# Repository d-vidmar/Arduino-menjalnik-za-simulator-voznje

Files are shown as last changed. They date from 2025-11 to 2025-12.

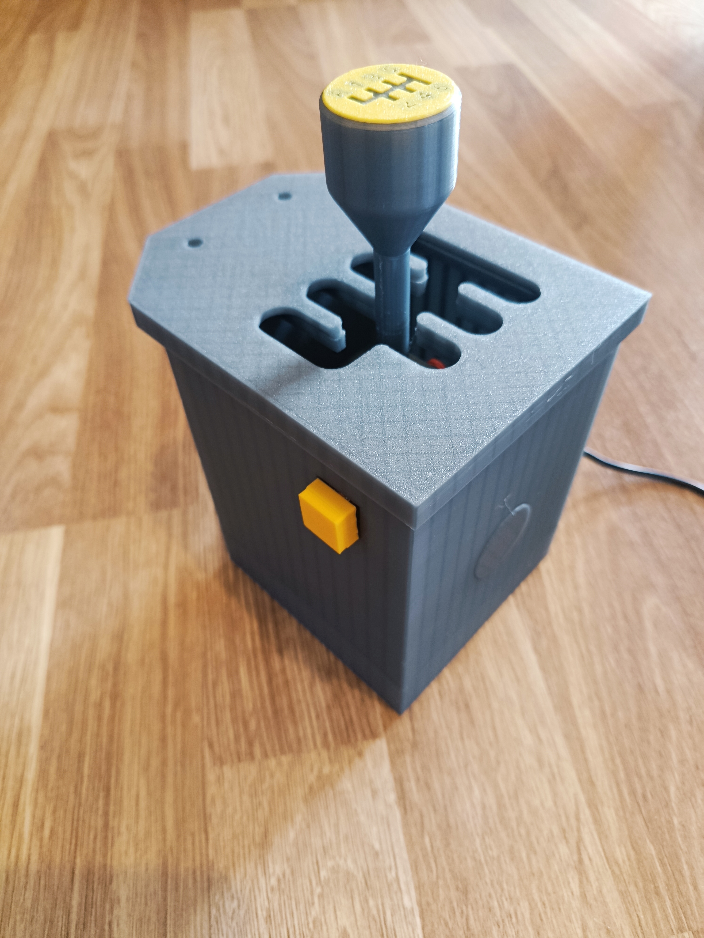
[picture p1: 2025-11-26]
slika.jpg

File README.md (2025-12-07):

# Arduino-menjalnik-za-simulator-voznje
Modeli za 3D tiskalnik in Arduino koda, s katero lahko Arduino Leonardo spremenite v menjalnik za simulator vožnje s 6 prestavami + R in dodatnim gumbom!

POMEMBNO: Uporabite lahko le Arduino Leonardo, Micro ali druge mikrokontrolerje, ki so na [TEM SEZNAMU](https://github.com/MHeironimus/ArduinoJoystickLibrary/wiki/Supported-Boards). Arduino Uno NE dela!
Potrebujete tudi [TO KNJIŽNJICO](https://github.com/MHeironimus/ArduinoJoystickLibrary/archive/master.zip). <br/><br/>

## Seznam stvari, ki jih potrebujete (poleg 3D tiskalnika in spajkalnika)
- 1x Arduino Leonardo / Pro Micro / drugi mikrokontroler z zgornjega seznama
- 2x potenciometer 10kOhm ([amazon](https://www.amazon.de/dp/B00H969CM0?ref_=pe_111929571_1111661321_t_fed_asin_title&th=1))
- 1x tipka za mehansko tipkovnico 
- 1x navojna palica M6 dolžine 8,5cm
- 2x elastika
- nekaj izoliranih tankih žic za povezave <br/><br/>

**Vsa navodila najdete v pdf datoteki "Navodila za izdelavo", vse povezave pa v datoteki "povezave.png".** <br/><br/>
Tako naj bi izgledal sestavlje menjalnik: <br/>
menjalnik_projekt

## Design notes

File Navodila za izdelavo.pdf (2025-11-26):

# Navodila za izdelavo

1. Natisnite vse dele.
2. Na oba potenciometra s spajkalnikom pritrdite žice, kot je na shemi. Žic še ne povezujte na Arduino.
3. V del »glavniDel« vstavite del »ročica« tako, kot je prikazano na sliki.

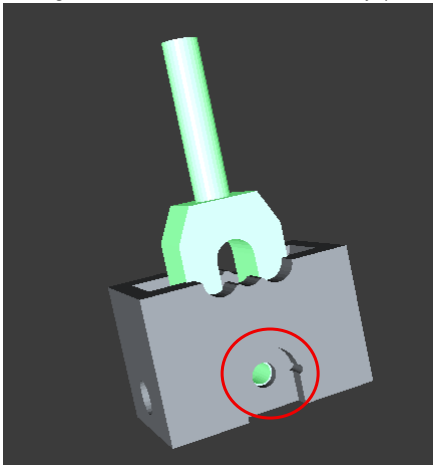
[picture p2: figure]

4. V označen del na sliki vstavite potenciometer tako, da se ob premikanju ročice vrti glava potenciometra.
5. Na drugo stran »glavnega dela« vstavite del »čep1«.
6. V odprtino »ročice« vstavite »čep3«. Elastiko vstavite v zarezo na eni strani »čepa3«, nato pojdite okoli »glavnega dela« in jo vstavite v zarezo na drugem koncu »čepa3«. (Glej sliko)

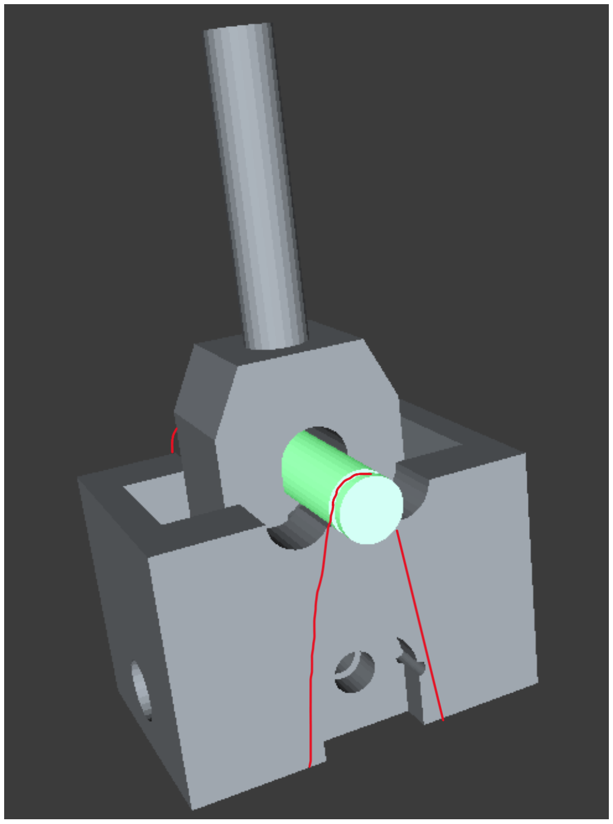
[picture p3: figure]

7. V manjšo, 6mm luknjo na »glavnem delu« vstavite glavo drugega potenciometra.
8. Drugi del potenciometra prilepite v označen del na »ohišju« nasproti večje luknje (glej spodnji sliki).

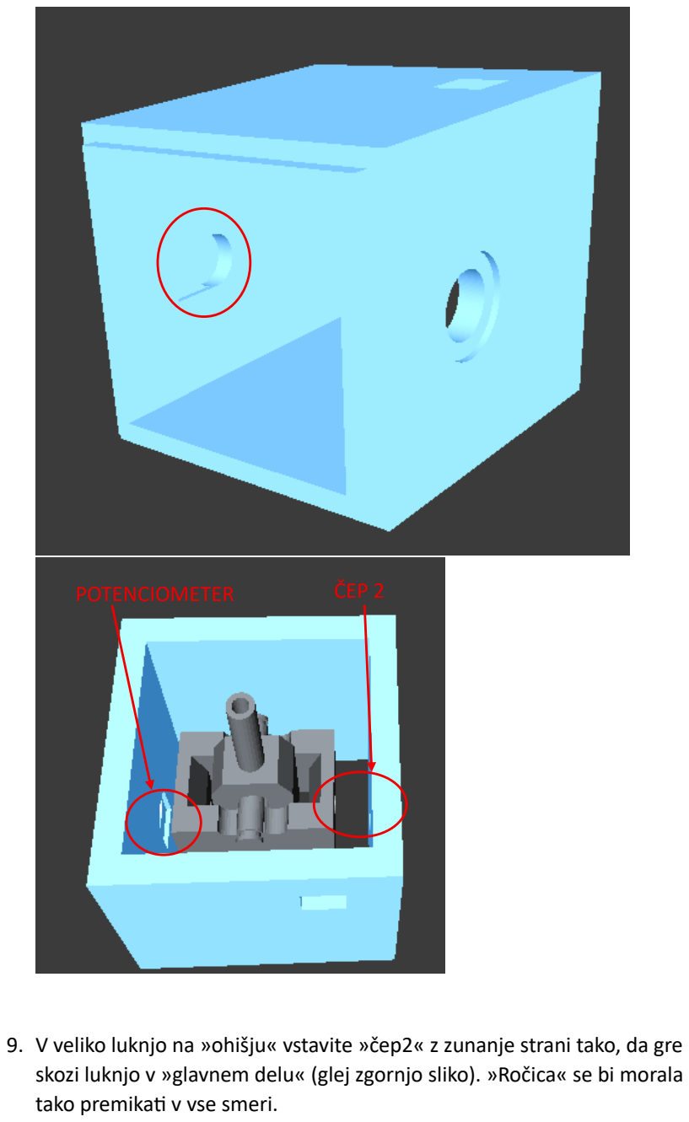
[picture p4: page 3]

9. V veliko luknjo na »ohišju« vstavite »čep2« z zunanje strani tako, da gre skozi luknjo v »glavnem delu« (glej zgornjo sliko). »Ročica« se bi morala tako premikati v vse smeri.

POTENCIOMETER

ČEP 2

10. Na tipko s spajkalnikom pritrdite žici. Nato jo z zunanje strani vstavite v kvadratno odprtino na »ohišju«. Na tipko pritrdite še del »tipka« in preverite, da je tipko mogoče pritisniti. Če se tipka zatika, jo je potrebno malo pobrusiti.
11. V »dno« pritrdite Arduino. Skozi luknjo na »dnesu« vstavite kabel in ga vtaknite v Arduino. Če se luknje za pritrditev na Arduinu ne prilegajo, ga lahko enostavno zalepite s silikonom.
12. Žice povežite na Arduino, kot je prikazano na shemi »povezave.png«.
13. »Dno« pritrdite na spodnji del »ohišja«, kjer je rob. »Dno« je pravilno obrnjeno tako, da je luknja za kabel na nasprotni strani od »tipke«. »dno« gre na »ohišje« zelo na tesno, če pa sploh ne gre, ga lahko malo pobrusite.
14. Na zgornjo stran »ohišja« pritrdite »zgornji del« tako, da je rob, ki ima dve luknji za pritrditev, na nasprotni strani od velike luknje na »ohišju«. Tudi ta del gre zelo na tesno, zato lepljenje verjetno ne bo potrebno.
15. V luknjo v »ročki« vstavite navojno palico M6 2,5 – 3cm globoko. »Ročko« z navojno palico nato vstavite v luknjo v »Ročici«. Če se »Ročka« vrti, jo lahko zalepite.

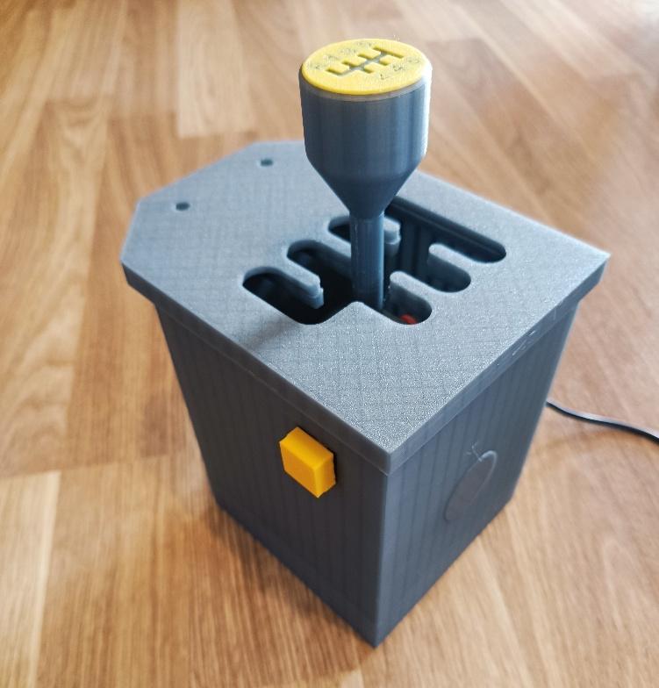
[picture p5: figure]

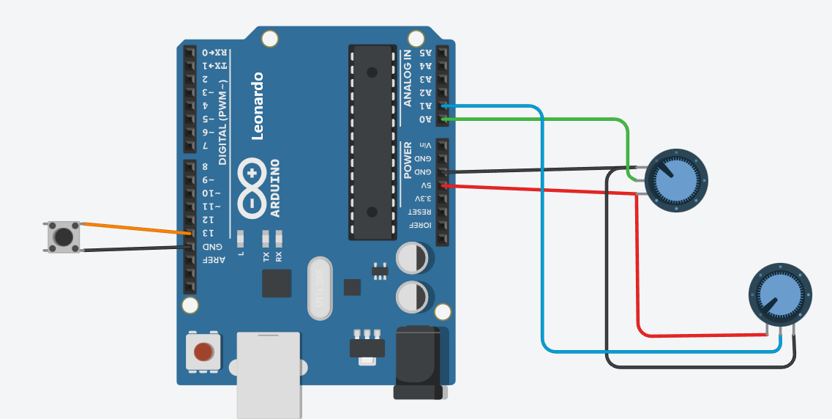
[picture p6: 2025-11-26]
povezave.png

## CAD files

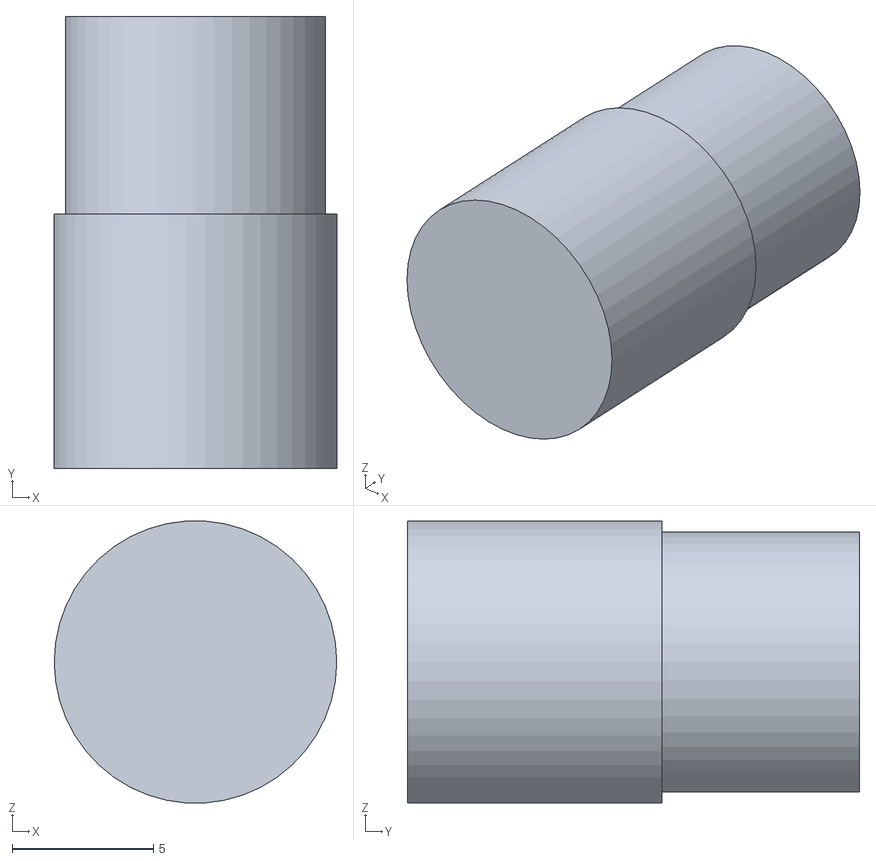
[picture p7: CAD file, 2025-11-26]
3DModeli/cep1.stl
10.0 x 16.0 x 9.98

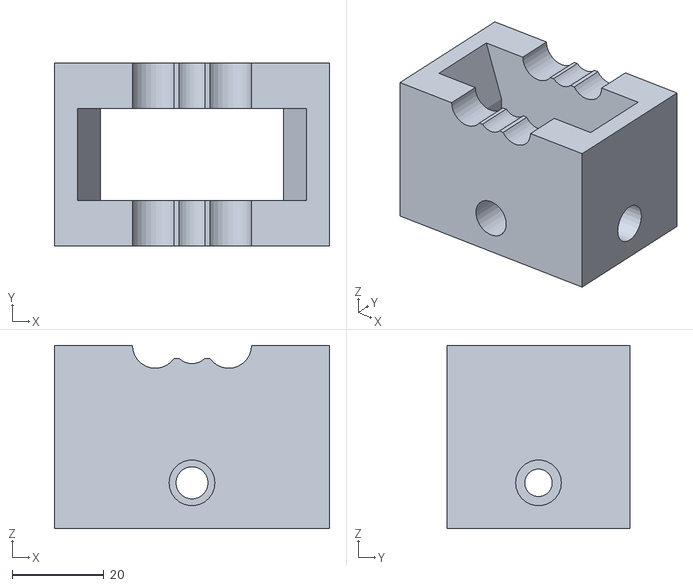
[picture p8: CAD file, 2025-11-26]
3DModeli/glavniDel.stl
60.0 x 40.0 x 40.0

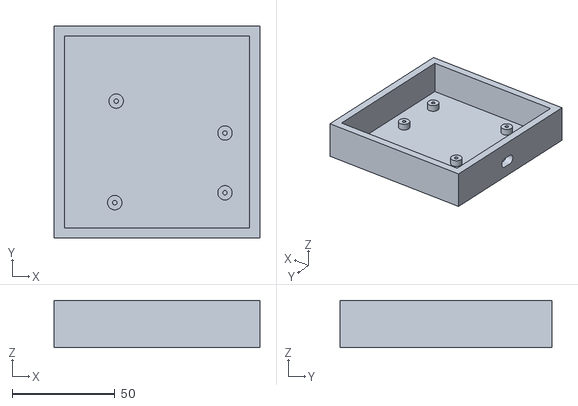
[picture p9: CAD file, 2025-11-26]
3DModeli/dno.stl
100.0 x 103.0 x 23.0

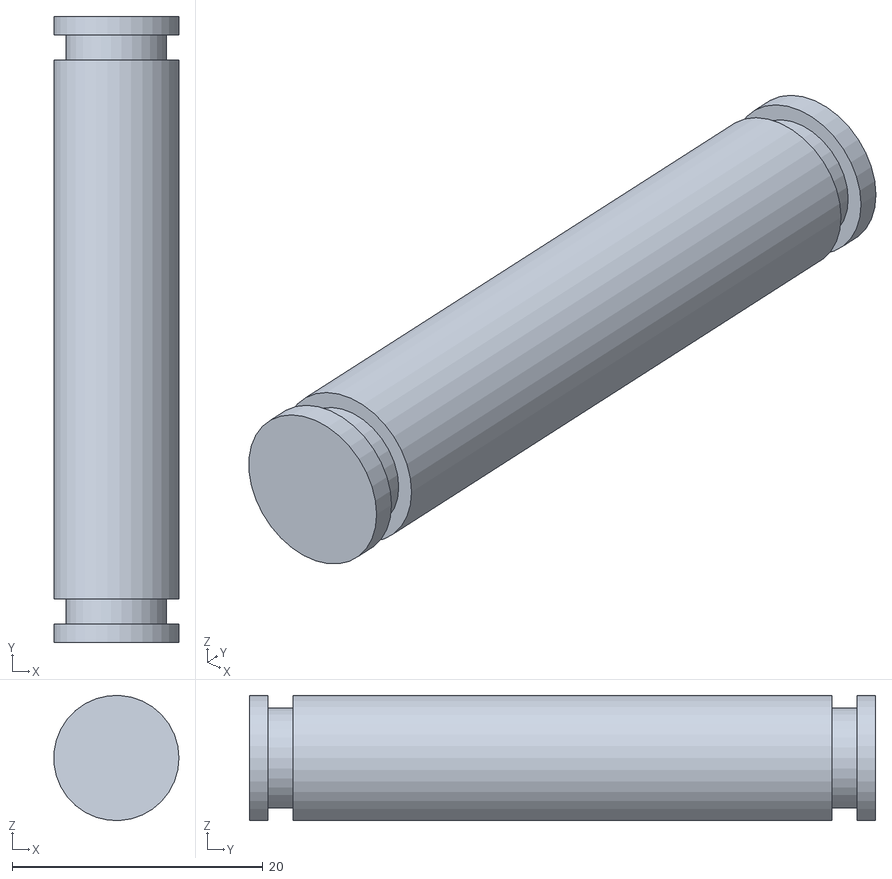
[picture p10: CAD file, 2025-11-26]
3DModeli/cep3.stl
9.98 x 50.0 x 9.99

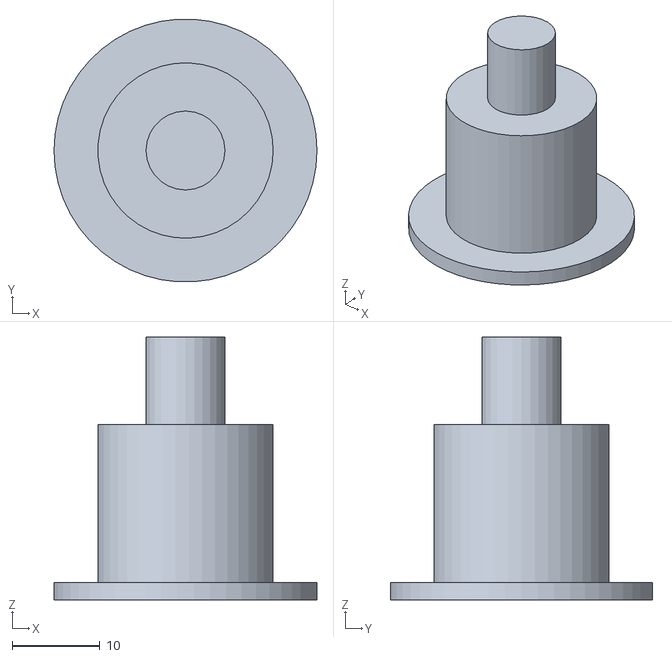
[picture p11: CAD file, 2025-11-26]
3DModeli/cep2.stl
30.0 x 29.9 x 30.0

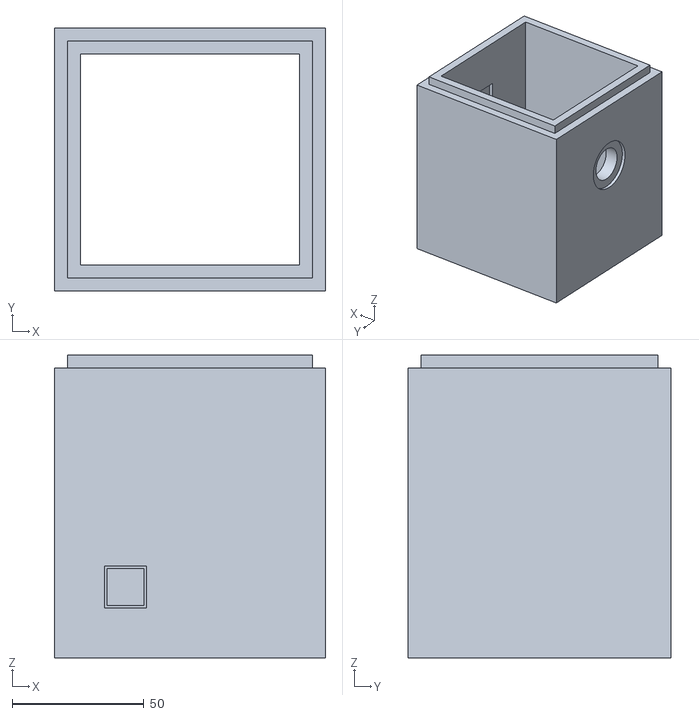
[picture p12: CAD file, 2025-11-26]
3DModeli/ohisje.stl
103.0 x 100.0 x 115.0

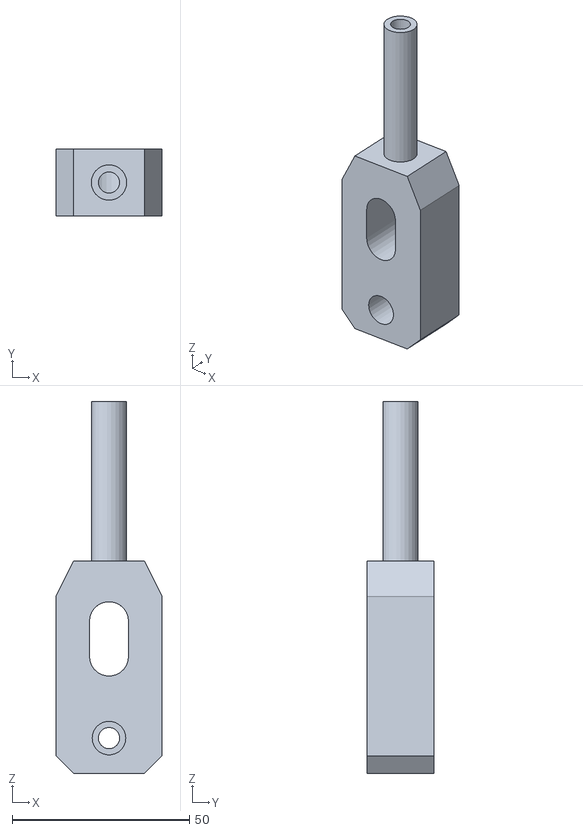
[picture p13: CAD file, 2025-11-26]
3DModeli/rocica.stl
30.0 x 19.0 x 105.0

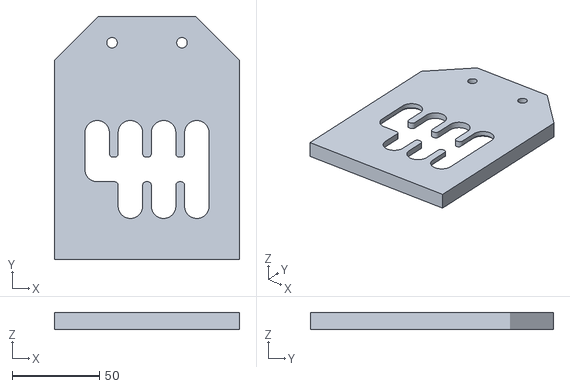
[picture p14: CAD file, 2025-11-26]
3DModeli/zgornjiDel.stl
106.0 x 139.0 x 10.0

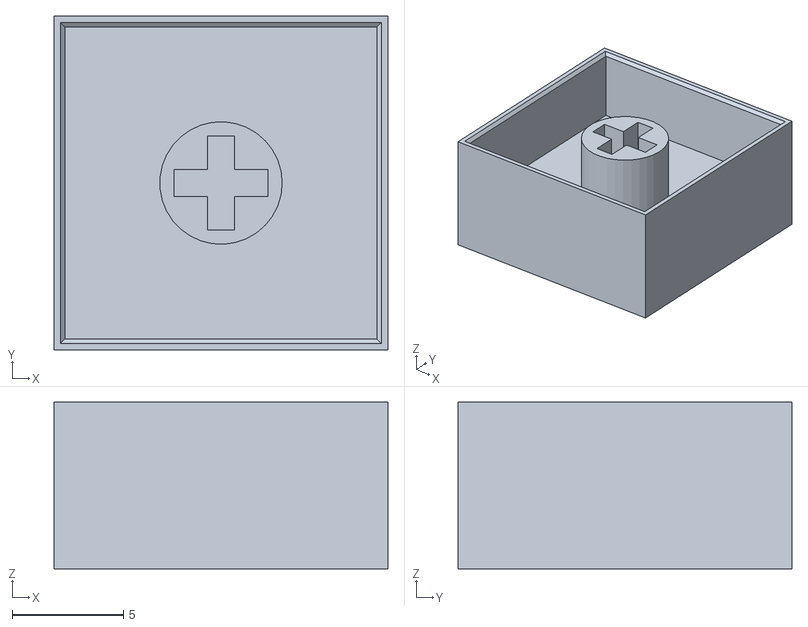
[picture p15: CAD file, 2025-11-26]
3DModeli/tipka.stl
15.0 x 15.0 x 7.50

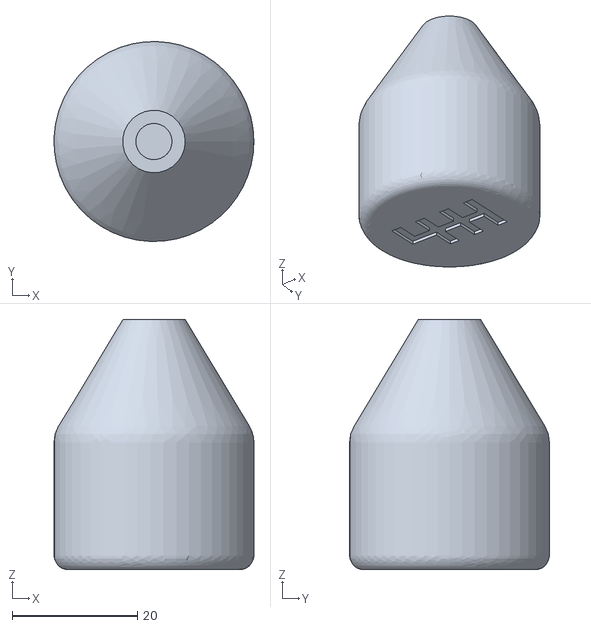
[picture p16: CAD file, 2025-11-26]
3DModeli/rocka.stl
32.0 x 32.0 x 40.0

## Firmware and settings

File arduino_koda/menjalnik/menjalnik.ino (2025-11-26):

// *** POMEMBNO ***
// Najprej je potrebno prenesti knjižnjico s te povezave: https://github.com/MHeironimus/ArduinoJoystickLibrary/archive/master.zip

#include "Joystick.h"

Joystick_ Joystick;

void setup() {
  pinMode(A0, INPUT);
  pinMode(A1, INPUT);
  pinMode(13, INPUT_PULLUP);
  Joystick.begin();
}

void loop() {
  int v=analogRead(A0);
  int h=analogRead(A1);
  if(digitalRead(13)==LOW){ //tipka pri strani
    Joystick.setButton(7,true);
  }
  else{
    Joystick.setButton(7,false);
  }
  
  //spremeni vrednosti pogojev tako, da ustrezajo vrednostim "v" in "h" potenciometrov, ko je prestava v določenem položaju
  //vrednosti "v" in "h" za tvoj primer dobiš tako, da odpreš datoteko "menjalnik.ino" in slediš navodilom.
  if(v<460&&h<480){ //R |spremeni pogoj tako, da je izpolnjen, ko je prestava v R položaju; enako velja za druge prestave
    Joystick.setButton(6,true);
    for(int i=0; i<6; i++){
      Joystick.setButton(i,false);
    }
  }
  else if(v<460&&h>480&&h<525){//1
    Joystick.setButton(0,true);
    for(int i=1; i<7; i++){
      Joystick.setButton(i,false);
    }
  }
  else if(v>490&&h>480&&h<525){//2
    Joystick.setButton(1,true);
    for(int i=0; i<7; i++){
      if(i!=1){
        Joystick.setButton(i,false);
      }
    }
  }
  else if(v<460&&h>525&&h<575){//3
    Joystick.setButton(2,true);
    for(int i=0; i<7; i++){
      if(i!=2){
        Joystick.setButton(i,false);
      }
    }
  }
  else if(v>490&&h>525&&h<575){//4
    Joystick.setButton(3,true);
    for(int i=0; i<7; i++){
      if(i!=3){
        Joystick.setButton(i,false);
      }
    }
  }
  else if(v<460&&h>575){//5
    Joystick.setButton(4,true);
    for(int i=0; i<7; i++){
      if(i!=4){
        Joystick.setButton(i,false);
      }
    }
  }
  else if(v>490&&h>575){//6
    Joystick.setButton(5,true);
    for(int i=0; i<7; i++){
      if(i!=5){
        Joystick.setButton(i,false);
      }
    }
  }
  else{ //N
    for(int i=0; i<7; i++){
      Joystick.setButton(i,false);
    }
  }

  delay(50);

}

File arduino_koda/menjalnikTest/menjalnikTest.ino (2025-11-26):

// *** NAVODILA ***
// Naloži kodo na arduino in odpri "Serial monitor"
// Najprej pusti menjalnik v N in nato pritisni tipko pri strani, da se izpiše vrednost "v" in "h"
// Prestavi v položaj R in nato pritisni tipko pri strani, da se izpiše vrednost "v" in "h" pri prestavi R
// Tako naprej nadaljuj za prestave od 1 do 6 PO VRSTI in vsakič pritisni tipko, da se izpišejo vrednosti "v" in "h" za prestave.
// Ko končaš, si te vrednosti zapiši. Odpri datoteko "menjalnik.ino" in popravi v njej pogoje po navodilih v tisti datoteki.



int state=0, i=0;
String tab[8] = {"N","R","1","2","3","4","5","6"};

void setup() {
  pinMode(A0,INPUT);
  pinMode(A1,INPUT);
  pinMode(13,INPUT_PULLUP);
  Serial.begin(9600);
}

void loop() {
  if(digitalRead(13)==LOW && state==0 && i<8){
    Serial.print(tab[i]+": ");
    Serial.println(String(analogRead(A0))+" v");
    Serial.println("   "+String(analogRead(A1))+" h");
    Serial.println();
    state=1;
    i++;
  }
  else{
    if(digitalRead(13)==HIGH){
      state=0;
    }
  }
  delay(50);

}
